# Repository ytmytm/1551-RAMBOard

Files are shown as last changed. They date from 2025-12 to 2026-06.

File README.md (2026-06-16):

# 1551-RAMBOard (First Bank)

This project adds **8K of RAM** and **8K of extra ROM space** to a **Commodore 1551** disk drive by replacing the ROM with a small daughterboard. The extra memory is used by a ROM patch to implement a simple **track cache**: read an entire track once, then serve subsequent sector reads from RAM.

A 27x (relative to 1541) / 7x (relative to 1551) fastloader is provided.

The mod and patched ROM are detected and utilized by [Parobek ROM](https://github.com/ytmytm/plus4-parobek).

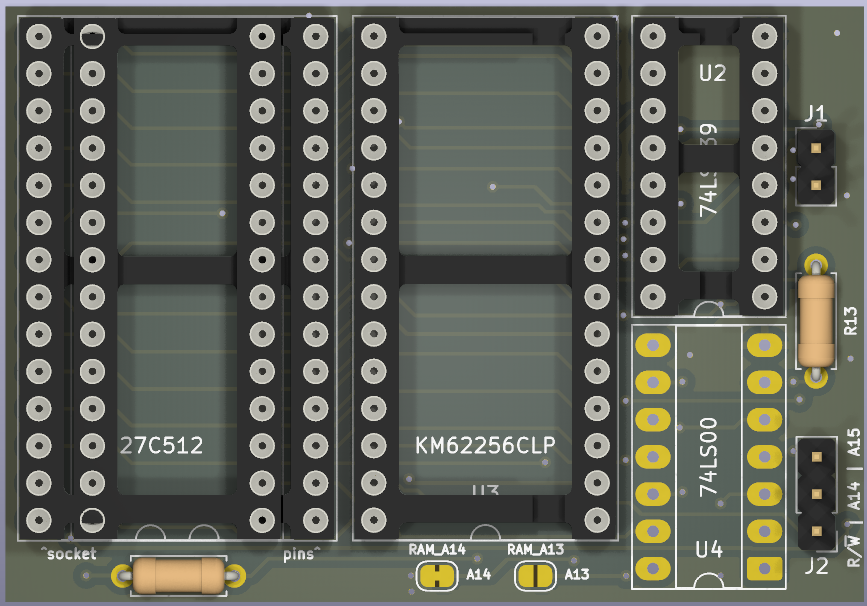
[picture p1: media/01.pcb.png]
1551-RAMBOard PCB


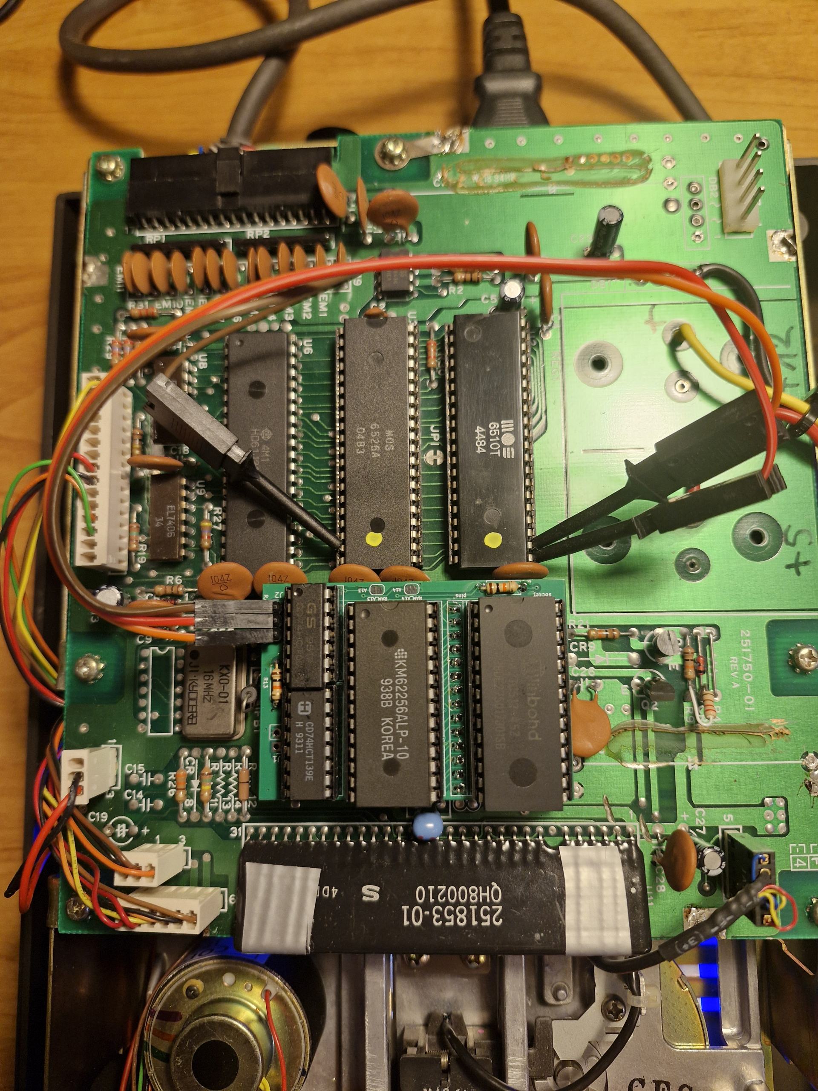
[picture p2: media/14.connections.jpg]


<a href="https://www.pcbway.com/project/shareproject/1551_RAMBOard_c846331a.html">PCB from PCBWay</a>

## What you get

- **RAM expansion**: `$8000-$9FFF` (8K) mapped to SRAM on the daughterboard.
- **Extra ROM window**: `$A000-$BFFF` (8K) mapped to the *upper* part of a larger ROM image.
- **Two DOS ROMs**: with a 64K ROM chip, you can add a switch to select either the stock 1551 ROM or the patched ROM
- **Two patched variants**: stock 1551 (318008-01) and [SuperDOS](https://plus4world.powweb.com/dl/utils/s/super_dos_1551.rom) (40-track disks)
- **HypaRAM**: fastloader
- **Parobek support**: even faster fastloader startup when drivecode is embedded in patched ROM

## Videos

<a href="https://www.youtube.com/watch?v=vWi2URbmIlo" target="_blank">
 Parobek loading 108 block file<small>Click for 1551 demonstration, loading a 108 block file</small></p>
</a>

<a href="https://www.youtube.com/watch?v=xZMYda7cszA" target="_blank">
 HypaRAM loading 220 block file<small>Click for Pi1551 HypaRAM demonstration, loading a 220 block file</small></p>
</a>

## Hardware

This board plugs into the original ROM socket and adds:

- **SRAM**: 8Kx8 (6264) or 32Kx8 (e.g. 62256). Only 8K is used by default; the remaining space is reserved for future banking options.
- **ROM**: 27C512/27E512 (64K). The board maps the active 32K half into `$8000-$FFFF`, but `$8000-$9FFF` is covered by RAM, so effectively the ROM is visible at `$A000-$FFFF` (24K). This is exactly the same setup as DolphinDOS on 1571
- **Glue logic**: `74LS139` + `74LS00`.

### BOM

- 1x 14-pin DIP socket
- 1x 16-pin DIP socket
- 2x 28-pin DIP socket
- 2x 14-pin round pinheaders ("precision" ones)
- 2x 10K resistors
- 1x 74LS00 (or HCT)
- 1x 74LS139 (or HCT)
- 1x 27E256 / 27E512 (32K or 64K EEPROM)
- 1x 6264 or 62256 (8K or 32K SRAM)
- 1x switch (for ROM selection: open or closed)

### Assembly

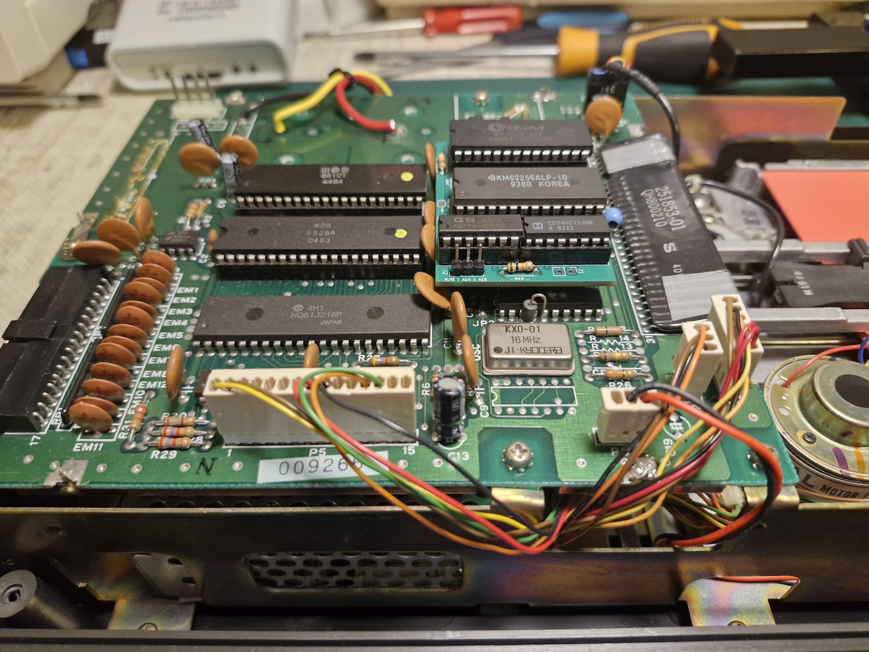
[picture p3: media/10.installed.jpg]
RAMBOard installed in a 1551


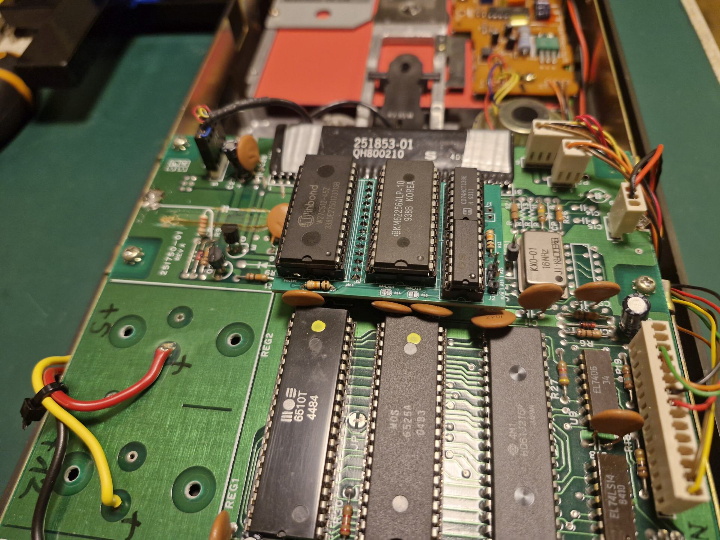
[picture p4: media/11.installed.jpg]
RAMBOard installed in a 1551


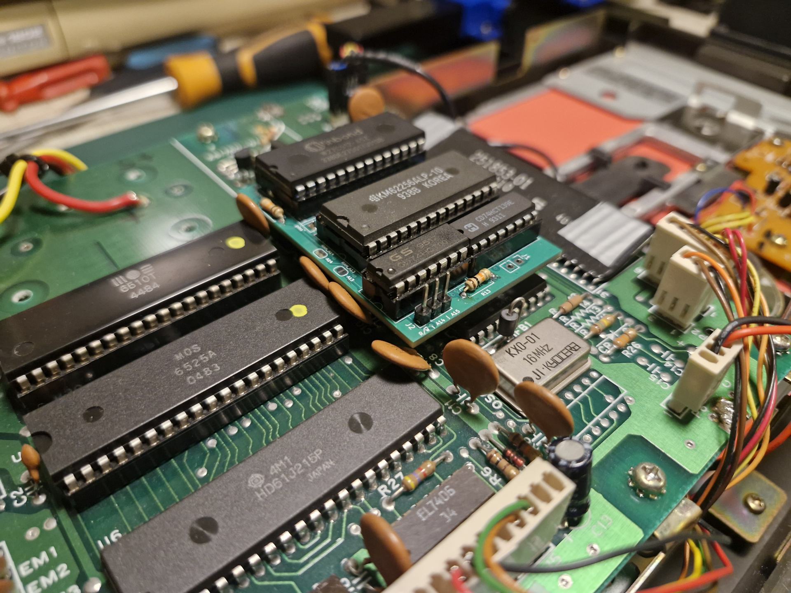
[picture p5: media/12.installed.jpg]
RAMBOard installed in a 1551


1. Start by soldering the pin headers to the holes marked "pins". Make sure their longer sections point toward the bottom. The board uses these to plug into the existing ROM socket.

2. Solder the remaining components: two resistors, then the sockets.

3. Flash the EEPROM with a ROM image from the Releases tab (or build your own with `make`). Use `1551.318008-01-64k.bin` for stock DOS or `super_dos_1551-64k.bin` for SuperDOS 40-track support. The 64K image contains the patched ROM in the top half (selected by default when `J1` is open), so you do not need to connect the switch yet.

4. Insert the chips into their sockets.

5. Open the 1551, remove the ROM chip (U4), and plug the board in its place. Ensure correct pin alignment.

6. Connect the remaining signals—`A14`, `A15`, and `R/~W`—as described in the Wiring section below.

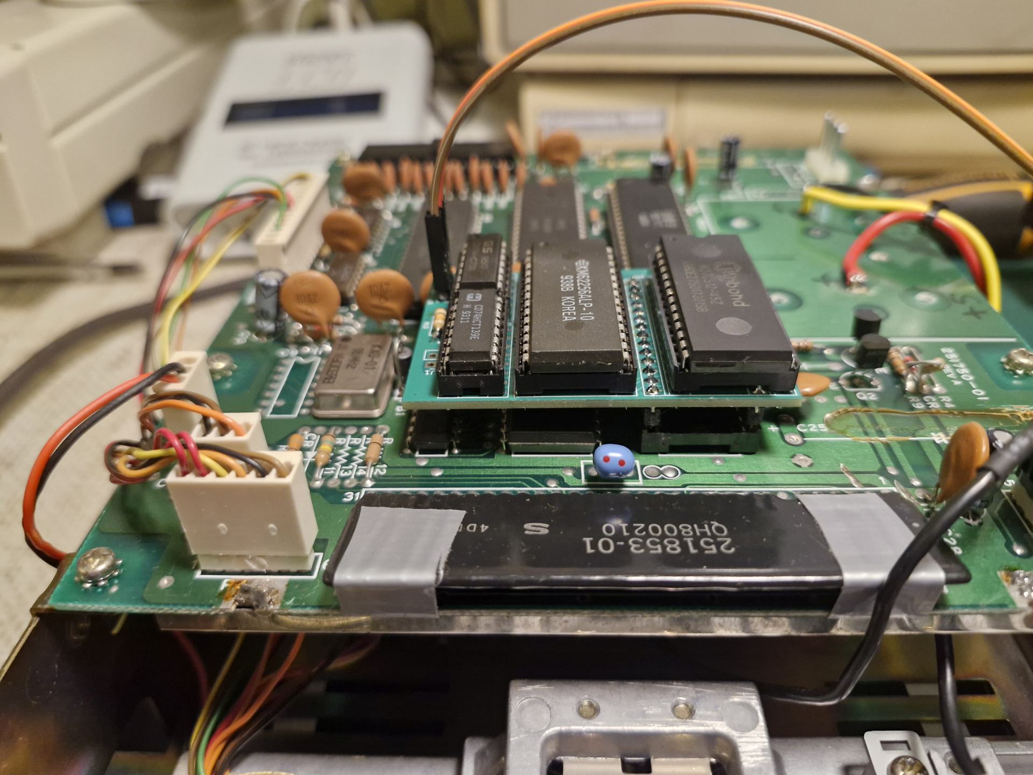
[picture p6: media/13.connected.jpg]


RAMBOard installed in a 1551

### Wiring

- **J1 (ROM bank select for 27C512)**:
  - **short**: bottom 32K of the 64K ROM
  - **open**: top 32K of the 64K ROM
- **J2 (3-wire tap from the 1551 mainboard)**:
  - **A14** from CPU **U2 pin 21** (or **U7 pin 7**)
  - **A15** from CPU **U2 pin 22** (or **U7 pin 6**)
  - **R/~W**: **do not** take raw R/W directly from the CPU. Use the qualified R/~W that actually goes to RAM:
    - onboard RAM **U5 pin 21**, or
    - **U3 pin 19**

### Jumpers

`RAM_A13` and `RAM_A14` jumpers are configured in such a way that you can plug in either SRAM 6264 (8K) or 62256 (32K) with no other changes.
If a method to latch two bits for the necessary port selection is found, then with 62256 (32K) four banks of 8K could be selected - e.g. for a permanent cache of the directory track.

### Quickstart

1. Install the hardware and keep J1 open
2. Use a 27E512 ROM with a 64K image from Releases (`1551.318008-01-64k.bin` or `super_dos_1551-64k.bin`)
3. Try running a simple BASIC program to read the ROM at `$a000` - with J1 open it should be the top, patched half with `RAM` signature
4. If you see `RAM` in the output and you can load the directory then everything works - directory track was already put into cache

```
10 open 15,8,15,"m-r"+chr$(0)+chr$(160)+chr$(3)
20 for i=1 to 3
30 get#15,b$
40 print asc(b$);b$
50 next
60 close 15
```

## Project files (KiCad)

Everything you need is attached to the Release page too.

- [KiCad project](kicad/1551-RAMBoard-FirstBank/)
- [Schematic PDF](kicad/1551-RAMBoard-FirstBank/plots/1551-RAMBoard2-FirstBank.pdf)
- [Gerbers](kicad/1551-RAMBoard-FirstBank/plots/)

## Firmware patch / build

The patcher is a single KickAssembler source file: `rampatch.asm`. It can patch either the stock 1551 ROM or SuperDOS 1551; the Makefile selects the base ROM via KickAssembler `-define` flags (`ROM1551` or `SUPERDOS1551`).

SuperDOS is the only other common 1551 DOS alternative. It adds 40-track disk support (similar in spirit to C64 SpeedDOS/DolphinDOS). The RAMBOard hook sites do not overlap with SuperDOS changes, so the same track-cache patch applies cleanly. Patch4 (ROM checksum bypass) is omitted for the SuperDOS build because SuperDOS already NOPs that routine.

### Source ROMs

Place these in `rom/` (or let `make` download them):

| File | Description |
|---|---|
| `rom/1551.318008-01.bin` | Stock 1551 DOS ([zimmers.net](https://www.zimmers.net/anonftp/pub/cbm/firmware/drives/new/1551/1551.318008-01.bin)) |
| `rom/super_dos_1551.bin` | SuperDOS 1551, 40 tracks ([plus4world](https://plus4world.powweb.com/dl/utils/s/super_dos_1551.rom)) |

### Windows (build.bat)

**Requirements**

- Java
- [KickAssembler](http://www.theweb.dk/KickAssembler/Main.html#frontpage) at `tools/KickAss.jar`
- Stock 1551 ROM at `rom/1551.318008-01.bin`

**Build**

```bat
build.bat
```

This builds the stock-ROM variant only:

- `1551.318008-01-patched.bin` — patched 32K ROM image
- `1551.318008-01-64k.bin` — 64K EPROM image (stock ROM in the lower half, patched ROM in the upper half)

For the SuperDOS variant, use the Linux Makefile (or invoke KickAssembler manually with `-define SUPERDOS1551`).

### Linux (Makefile)

**Requirements**

- `make`
- Java
- [KickAssembler](http://www.theweb.dk/KickAssembler/Main.html#frontpage) at `tools/KickAss.jar`
- [ACME](https://sourceforge.net/projects/acme-crossass/) assembler (`acme`)
- `curl` or `wget` (optional; used to auto-download source ROMs)

**Build everything**

```sh
make
```

This produces all deliverables:

| Output | Description |
|---|---|
| `1551.318008-01-patched.bin` | Patched 32K ROM (stock 1551 base) |
| `1551.318008-01-64k.bin` | 64K EPROM image (stock + patched) |
| `super_dos_1551-patched.bin` | Patched 32K ROM (SuperDOS 40-track base) |
| `super_dos_1551-64k.bin` | 64K EPROM image (SuperDOS + patched) |
| `hyparam_1551.prg` | HypaRAM fastloader wedge |

**Other targets**

```sh
make help          # list all targets
make superrom      # SuperDOS patched 32K + 64K images only
make clean         # remove all build outputs (keeps source ROMs in rom/)
make test          # VICE xplus4 with stock patched ROM + RAM expansion
make test-super    # VICE xplus4 with SuperDOS patched ROM + RAM expansion
```

Each 64K image is suitable for 27C512/27E512 EPROMs:

- First 16K: `$FF` bytes (EPROM neutral)
- Next 16K: unpatched base ROM (stock or SuperDOS)
- Upper 32K: patched ROM with track cache and fastloader

## HypaRAM fastloader wedge

An example fastloader wedge called **HypaRAM** is included in the `src/` directory as `hypainstall14f0.s`, which
generates `hyparam_1551.prg`.

When loaded it will intercept LOAD operations and will run the fastloader embedded in the patched drive ROM directly.
With track cache the speedup is approximately **27x** relative to 1541 and **7x** relative to stock 1551.

For simplicity it supports only device #8 and doesn't check if the ROM was patched.

The same fastloader is embedded in [Parobek ROM](https://github.com/ytmytm/plus4-parobek) and will be autodetected for LOAD operations.

### Building HypaRAM

To build the binary `hyparam_1551.prg`, you need the [ACME assembler](https://sourceforge.net/projects/acme-crossass/).

- **Windows**:  
  ```
  acme hypainstall14f0.s
  ```

- **Linux/Unix/WSL**:  
  ```
  make
  ```

The produced binary `hyparam_1551.prg` can be loaded into C16/+4 emulators or real hardware with the RAMBoard installed.

## Testing in VICE

This repo contains `docs/vice-1551-ram-expansion.patch`, which documents the changes needed for VICE to emulate:

- 1551 RAM expansion at `$8000-$9FFF`
- the 32K ROM mapping with RAM overlay

## ROM signature / API stub

The patched ROM contains a small fixed-location signature and a public jump table:

- `$A000-$A002`: ASCII signature `"RAM"` (used to detect that the patched ROM is active)
- `$A003...`: jump table entries

This is used by the HypaRAM fastloader and [Parobek ROM](https://github.com/ytmytm/plus4-parobek).

## Theory of operation

### Address space

The onboard logic enables ROM only in `$C000-$FFFF` range. We ignore this signal and instead use CPU's A15 line as a trigger which signals that `$8000-$FFFF` range is being accessed.

The 74LS139 logic uses A14 to further divide that range to generate chip select signals for RAM in `$8000-$9FFF` range and for ROM in `$A000-$FFFF`.

### Track cache logic

When the drive firmware requests a sector read:

- If the requested track is already cached, the sector is copied from expanded RAM into the target buffer and execution returns to the original ROM flow.
- Otherwise, the patched code reads the entire track, caching **decoded sector data** in expanded RAM and collecting sector numbers from headers to build the lookup table.

The whole track is captured within **one disk revolution** (about **200 ms at 300 rpm**).

### GCR decoding on 1551

Unlike 1541-class drives, the 1551 ROM already decodes GCR **on the fly** during reads (made possible by the 2 MHz CPU). The patch reuses the same approach.

## Related

- design for 1541: [**1541-RAMBOard**](https://github.com/ytmytm/1541-RAMBOardII)
- design for 1571: [**1571 Track Cache ROM**](https://github.com/ytmytm/1571-TrackCacheROM)

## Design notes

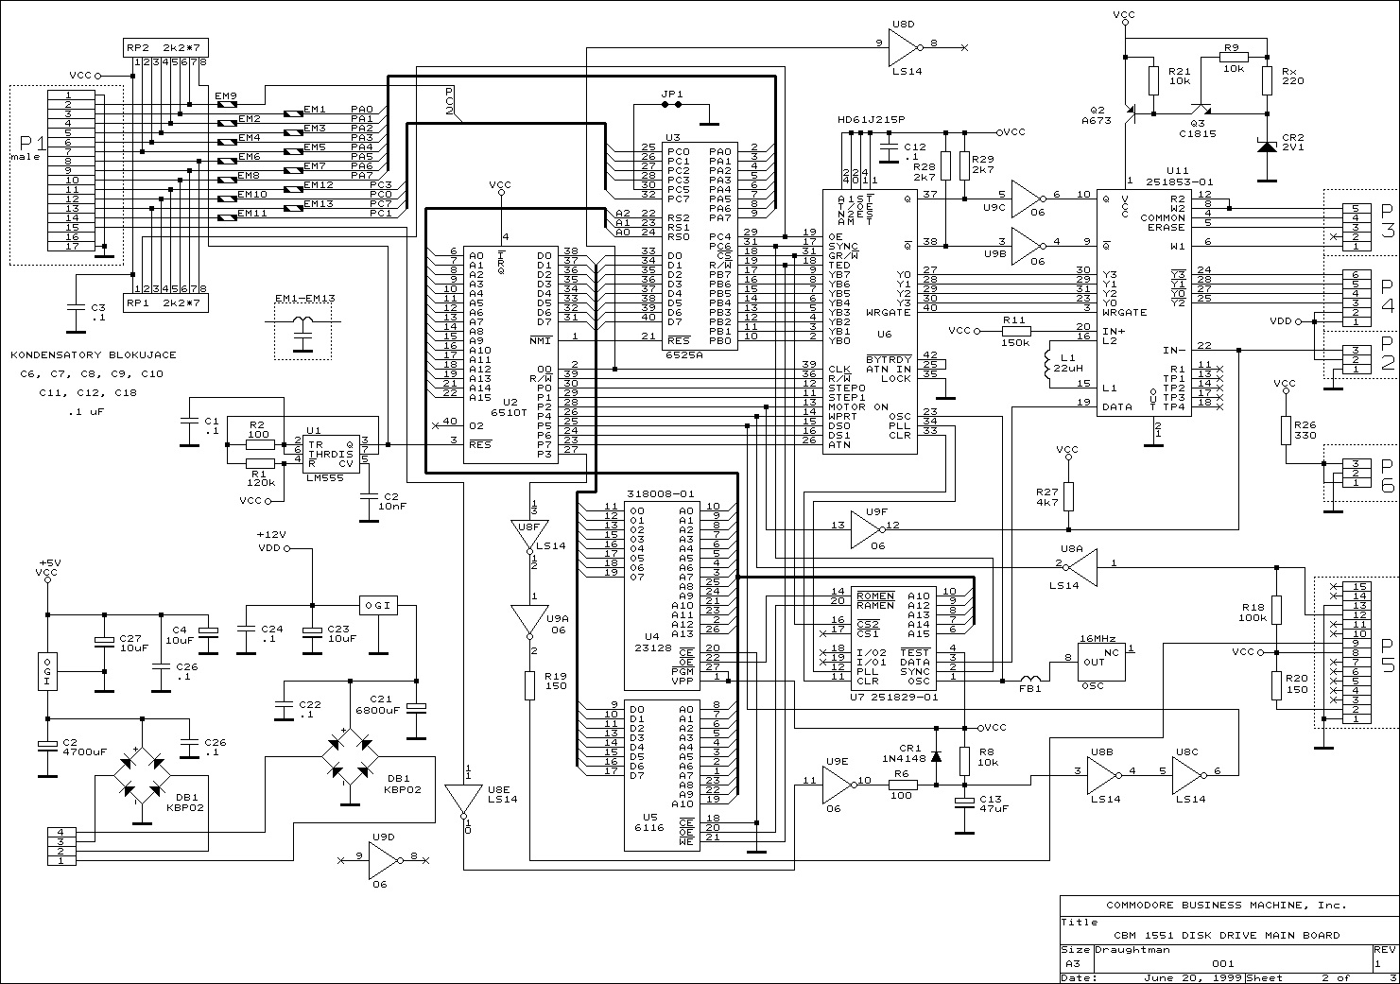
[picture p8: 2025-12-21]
doc/1551-schematic-main.gif

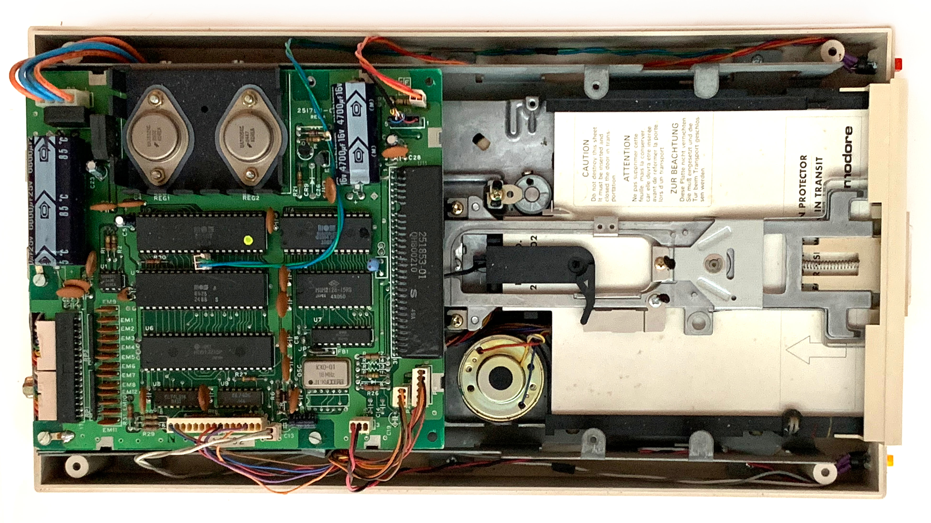
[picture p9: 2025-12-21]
doc/1551-1570_inside.jpg

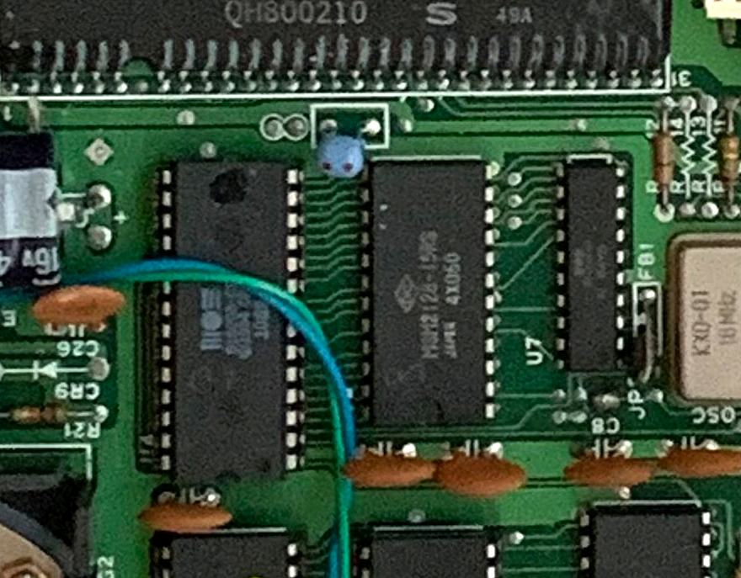
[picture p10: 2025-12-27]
doc/1551-1570_inside-trim.jpg

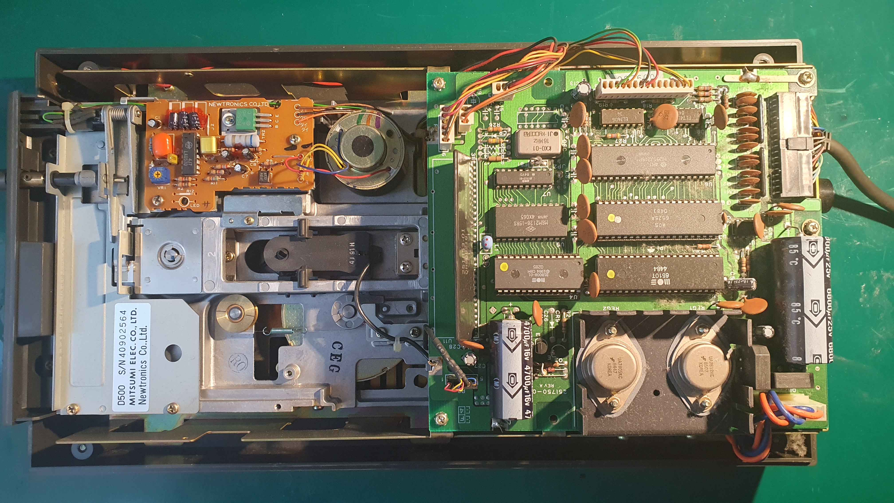
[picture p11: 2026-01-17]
doc/nightrider-1551-1.jpg

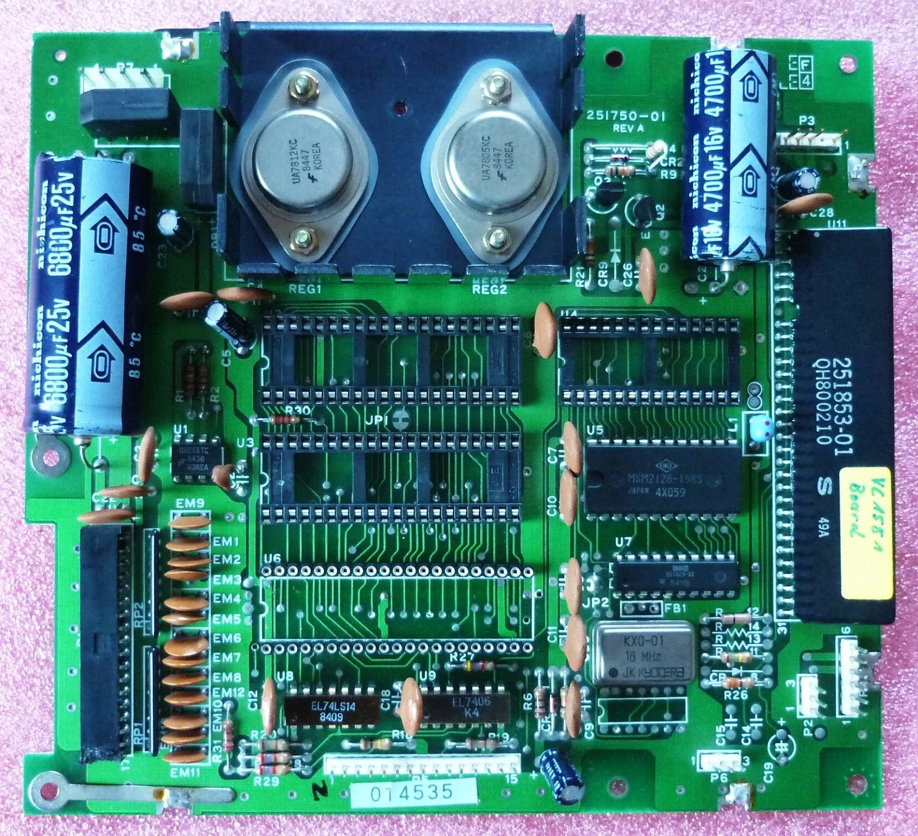
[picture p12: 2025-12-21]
doc/1551-s-l1600.jpg

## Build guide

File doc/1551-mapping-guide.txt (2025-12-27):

(Note: this is an automatic comparison based on 1551 disassembly and All About Your 1541
       trust but verify!)

COMMODORE 1541 TO 1551 ROM MAPPING GUIDE
========================================

This document provides a comprehensive mapping between the Commodore 1541 and 1551 ROMs
to facilitate porting low-level patches (like RAMBoard/RAMEXP patches).

1. ZERO PAGE MAPPING
--------------------
The 1551 zero page is significantly shifted compared to the 1541.

| Description | 1541 Addr | 1551 Symbol | 1551 Addr |
|---|---|---|---|
| Active Track Pointer | $32 | zp20 | $20 |
| Active Sector Pointer | $33 | zp21 | $21 |
| Buffer Pointer (Current) | $30-$31 | zp27-$28 | $27-$28 |
| Header ID 1 & 2 | $16-$17 | zp18-$19 | $18-$19 |
| Header Track | $18 | zp1A | $1A |
| Header Sector | $19 | zp1B | $1B |
| Header Checksum | $1A | zp1C | $1C |
| Data Block ID (default $07) | $47 | zp41 | $41 |
| Data Parity (Checksum) | $3A | zp30 | $30 |
| Current Drive Number (always 0) | $7F | zp78 | $78 |
| GCR conversion offset | $34 | zp2D | $2D |
| GCR conversion pointer | $2E-$2F | zp1E-$1F | $1E-$1F |
| GCR byte counter | $36 | zp2E | $2E |
| GCR buffer pointer | $4E-$4F | zp36-$37 | $36-$37 |

Note: 1551 has "free" ZP space at $F0-$FF and around $60-$6F (though check disassembly).

2. HARDWARE I/O MAPPING
-----------------------
The 1551 replaces VIAs with a TIA chip ($4000) and CPU Port ($00/$01).

| Feature | 1541 (VIA) | 1551 (TIA/Port) | Logic Difference |
|---|---|---|---|
| Data Input | $1C01 | $4001 | TIA read register |
| SYNC Found | $1C00 bit 7 | $4002 bit 6 | 1551: 0 = SYNC found |
| Byte Ready | $1800 (CA1) | $01 bit 7 | 1551: 1 = Byte Ready |
| Motor / LED | $1C00 bits 2/3  | $01 bits 2/3 | Same bit positions |
| Stepper Motor | $1C00 bits 0/1  | $01 bits 0/1 | Same bit positions |
| R/W Mode | $1C00 bit 5 | $4002 bit 4 | 0=Write, 1=Read |

3. ROM FUNCTION MAPPING
-----------------------
Addresses refer to stock 1541-II ($C000-$FFFF) and 1551 ($C000-$FFFF).

| 1541 Routine | 1541 Addr | 1551 Addr | 1551 Symbol | Notes |
|---|---|---|---|---|
| Read Sector | $F4D1 | $F403 | B_F403 | Main sector read entry point |
| Wait for Data Block| $F50A | $F513 | S_F513 | Wait for header sync + sync |
| Wait for Header | $F510 | $F519 | S_F519 | Look for specific track/sector header|
| Wait for SYNC | $F556 | $F560 | L_F560 | Simple wait for SYNC mark |
| Encode Header | $F934 | $F3BB | S_F3BB | Result goes to $0111 on 1551 |
| Calculate Parity | $F5E9 | $F60A | S_F60A | Result in A and zp30 |
| Error Termination  | $F969 | $FA12 | L_FA12 | Exit to main loop with error in A |
| Initialize Drive | $D005 | $C4B7 | S_C4B7 | Disk initialization routine |
| 5 GCR to 4 BIN | $F7E6 | $F928 | S_F928 | Fast GCR decoding routine |
| ROM Checksum Check | $EAE4 | $E9F0 | B_E9F0 | Site to disable ROM checksum |

4. CODE STRUCTURE COMPARISON (SECTOR READ)
------------------------------------------

1541 (Standard Sector Read loop):
---------------------------------
F4D1: 20 0A F5    JSR $F50A  ; Wait for data block
F4D4: AD 01 1C    LDA $1C01  ; Read data...

1551 (Standard Sector Read loop):
---------------------------------
F403: 20 13 F5    JSR $F513  ; Wait for block (S_F513)
F406: 24 01       BIT $01    ; Wait for byte ready (zp01 bit 7)
F408: 10 FC       BPL $F406
F40A: AD 01 40    LDA $4001  ; Read from TIA data register

5. PATCH ADVICE FOR 1551
------------------------
- Hooking Read Sector: Use $F403 instead of $F4D1.
- GCR Decoding: 1551 uses "on-the-fly" decoding in the ROM ($F406 onwards), unlike 1541 which reads the whole GCR block and decodes later ($F4ED).
- Checksum Disable: Disable at $E9F2 by NOPing the branch or forcing the comparison to pass.
- Free RAM: $0300-$06FF (4 buffers) is the same. BAM is resident at $0700-$07FF.

6. PROPOSED RAMPATCH-1551.ASM HEADER
------------------------------------
This is how the configuration section of `rampatch-1541.asm` translates to 1551.

```6502
// 1551 ROM patch configuration
// RAM expansion base address (e.g. $8000-$9FFF)
.const RAMEXP = $8000 

// Zero Page mapping (1551 equivalents)
.const HEADER = $18   // block header id 1 ($18-$1C: ID1, ID2, T, S, CHK)
.const HDRPNT = $20   // active track/sector pointer ($20/$21)
.const STAB   = $24   // scratch pad for GCR conversion ($24-$2B)
.const BUFPNT = $27   // current buffer pointer ($27/$28)
.const DBID   = $41   // data block ID char ($07)
.const CHKSUM = $30   // parity for data buffer (result of S_F60A)

// 1551 ROM locations
.const LC4B7 = $C4B7 // initialize drive if needed
.const LC722 = $C722 // initialize drive (raw entry)
.const LF560 = $F560 // wait for sync
.const LF928 = $F928 // convert 5 GCR bytes to 4 BIN
.const LF513 = $F513 // wait for encoded header & sync
.const LF406 = $F406 // instruction after patch at $F403
.const LF60A = $F60A // calculate parity of data block ($27 pointer)

// Patch variables (using verified free ZP in 1551)
.const bufpage     = $f0  // (2)
.const bufrest     = $f2  // (2) - only if caching raw GCR
.const hdroffs     = $f4  // (1)
.const counter     = $f5  // (1)
.const hdroffsold  = $f6  // (1)

// ROM Patch Sites
.const PATCH_READ_SECTOR  = $F403  // hook for ReadSector (was $F4D1)
.const PATCH_DISK_CHANGE   = $C722  // hook for ResetCache (was $C649)
.const PATCH_ROM_CHECKSUM  = $E9F0  // 6x NOP to disable check (was $EAE4)
.const PATCH_JOB_IRQ       = $F19F  // hook for InvalidateCacheForJob (was $F2C0)
.const PATCH_I_COMMAND     = $D121  // hook for InitializeAndResetCache (was $D005)

// Sizes (1551 uses same sector counts as 1541)
.const hdrsize     = 8
.const maxsector   = 22
.const bufrestsize = $48
```

7. DETAILED CORRESPONDENCE TABLE
-------------------------------

| Feature / Variable | 1541 Address | 1551 Address | 1551 Disasm Symbol |
|---|---|---|---|
| Disk ID 1 | $12 | $14 | zp14 |
| Disk ID 2 | $13 | $15 | zp15 |
| Header ID 1 | $16 | $18 | zp18 |
| Header ID 2 | $17 | $19 | zp19 |
| Header Track | $18 | $1A | zp1A |
| Header Sector | $19 | $1B | zp1B |
| Header Checksum | $1A | $1C | zp1C |
| Drive Status | $20 | $2B | zp2B |
| Current Track | $22 | $29 | zp29 |
| Current Sector | $4C | $3D | zp3D |
| Job Buffers | $00-$05 | $0002-$0007  | $0002-$0007 |
| Job Parameters | $06-$11 | $08-$13 | zp08-zp13 |
| DOS Error Flag | $0298 | $0298 | V_0298 |
| TIA Register Port  | $1C01 (VIA)  | $4001 (TIA)  | V_4001 |
| SYNC Status | $1C00 bit 7  | $4002 bit 6  | V_4002 (0=found)  |
| Byte Ready Status  | $1800 (CA1)  | $01 bit 7 | zp01 (1=ready) |
| Buffer Pointer | $9A (table)  | $9A (table)  | zp9A |
| Buffer Allocation  | $A8 (table)  | $A8 (table)  | zpA8 |
| Channel Index | $022B-$022D  | $022B-$022D  | V_022B |
| File Type | $ED (table)  | $ED (table)  | zpED |
| Channel Status | $F3 (table)  | $F3 (table)  | zpF3 |
| Blocks Free (lo) | $02FA | $02FA | V_02FA |
| Blocks Free (hi) | $02FC | $02FC | V_02FC |
| BAM Changed Flag | $0251 | $0251 | V_0251 |
| Command Flag | $0255 | $0255 | V_0255 |
| End Pointer | $0244 | $0244 | V_0244 |

8. GCR DECODING ANALYSIS
------------------------

### 8.1 On-the-fly Decoding
Unlike the 1541 (1MHz), which must read a whole track of raw GCR data and decode it later, the 1551 (2MHz) performs **on-the-fly GCR decoding** similar to the 1571.
- The TIA chip ($4001) latches the incoming GCR byte.
- The 2MHz CPU has enough cycles between bytes to decode the GCR nybbles using lookup tables.
- **Implication for RAMpatch**: In your `ReadTrack` routine, you should decode GCR into binary data *while reading*. This allows the cache to store ready-to-use binary data, significantly speeding up subsequent sector requests.

### 8.2 GCR Decoding Tables (1551 vs 1571)
You noticed that 1571 tables take 1KB while 1551 tables seem shorter.
- **1571 (4 Pages)**: The 1571 ROM ($9F0D-$A3FF) uses four separate 256-byte pages for GCR decoding. However, these pages are highly redundant (e.g., the same 64-byte sequence repeated 4 times per page).
- **1551 (1 Page)**: The 1551 ROM ($F6FF-$F7FF) uses an **overlapping table** technique. It fits the same decoding logic into a single 256-byte page by using different base addresses (offsets) into the same block of data.
  - 1571 `LA00D` (Page 0) -> 1551 uses base `$F70C,X`
  - 1571 `LA10D` (Page 1) -> 1551 uses base `$F70D,X` or `$F70E,X`
  - 1571 `LA20D` (Page 2) -> 1551 uses base `$F71C,X`
  - 1571 `LA30D` (Page 3) -> 1551 uses base `$F729,X`
- **Recommendation**: Do not bundle GCR tables in your 1551 patch. Use the existing tables in the 1551 ROM starting at `$F6FF`.

### 8.3 Comparison of GCR base addresses:
| 1571 Label | 1571 Addr | 1551 Equivalent Base | 1551 Addr |
|---|---|---|---|
| L9F0D | $9F0D | V_F70C | $F70C |
| L9F1D | $9F1D | V_F71C | $F71C |
| LA00D | $A00D | V_F70C | $F70C |
| LA10D | $A10D | V_F70D / V_F70E | $F70D/E |
| LA20D | $A20D | V_F71C | $F71C |
| LA30D | $A30D | V_F729 | $F729 |
| L9F2A | $9F2A | V_F729 | $F729 |

9. ADDITIONAL FUNCTION MAPPINGS
--------------------------------
Based on detailed analysis of the commented disassembly:

| 1541 Routine | 1541 Addr | 1551 Addr | 1551 Symbol | Notes |
|---|---|---|---|---|
| Open Channel (Read) | ~$D1FB | $D1FB | S_D1FB | Opens channel for reading files |
| Open Channel (Write) | ~$D217 | $D217 | S_D217 | Opens channel for writing files |
| Get File Type | ~$D235 | $D235 | S_D235 | Returns file type, Z flag if REL |
| Get Byte from Buffer | ~$D247 | $D247 | S_D247 | Reads next byte from channel buffer |
| Read Track/Sector Link | ~$D1AB | $D1AB | S_D1AB | Reads track/sector from linked file |
| Read/Write Block | ~$D1D3 | $D1D3 | S_D1D3 | Common entry for block operations |
| Main Wait Loop | ~$EAxx | $EABD | L_EABD | Idle loop waiting for commands |
| Periodic Maintenance | ~$EAxx | $EADC | S_EADC | Called every 256 idle loops |
| Clear Error Flag | ~$F3xx | $F3F0 | S_F3F0 | Clears V_026C error flag |
| Set LED Flag | ~$F3xx | $F3F7 | L_F3F7 | Sets LED flash mode ($E0) |
| Header Timeout | ~$F554 | $F554 | B_F554 | Header search timeout (error $02) |
| Sync Timeout | ~$F556 | $F55B | L_F55B | Sync wait timeout (error $03) |
| TCBM Bus Handler | N/A | $C022 | S_C022 | 1551-specific TCBM interrupt handler |
| TCBM TALK/LISTEN | N/A | $C071 | B_C071 | Handle TALK/LISTEN commands |
| TCBM Data Receive | N/A | $C0F6 | B_C0F6 | Handle incoming data |
| TCBM Data Send | N/A | $C14E | B_C14E | Handle outgoing data |

10. TCBM PROTOCOL DETAILS (1551-SPECIFIC)
------------------------------------------
The 1551 uses TCBM (TED Computer Bus Manager) instead of IEEE-488 serial bus.

TCBM Hardware Registers:
- $4000: TIA Port A (data port, bidirectional)
- $4001: TIA Data Latch (GCR bytes from disk)
- $4002: TIA Status/Control Register
  * Bit 6: SYNC found (0 = found, inverted logic vs 1541)
  * Bit 3: ACK handshake bit
  * Bits 6-7: Stepper motor control
- $4003: TIA Data Direction Register (0=input, $FF=output)
- $01: CPU Port (bit 7 = Byte Ready, bits 0-1 = stepper, bit 2 = motor, bit 3 = LED)

TCBM Command Codes:
- $40: TALK command
- $20: LISTEN command  
- $5F: UNTALK command
- $3F: UNLISTEN command
- $60: DATA (not a device command)

TCBM Handshake:
- DAV (Data Valid): Bit 7 of $4002 (negative logic: 0 = data valid)
- ACK: Bit 3 of $4002 (set/clear for handshake)
- Double-read technique: Read $4000 twice to ensure port stability

11. IRQ AND JOB QUEUE DIFFERENCES
----------------------------------
1541 IRQ ($F2C0):
- Triggered by IEEE-488 ATN line
- Processes job queue at $00-$05
- Checks for ATN commands from computer

1551 IRQ ($F195):
- Triggered by 555 timer (astable multivibrator)
- Frequency: According to disassembly, IRQ occurs every 16650 cycles
  * At 2MHz: 16650 cycles / 2000000 cycles/s = 8.325ms between IRQs
  * This theoretically gives ~120Hz (1/0.008325), BUT:
  * - There is no direct technical documentation confirming this frequency
  * - Some sources suggest ~100Hz (every 10ms)
  * - 555 timer may have tolerance, so actual frequency may vary
  * - Should be verified by measurement or technical documentation
- Processes job queue at $0002-$0007 (shifted by 2 bytes)
- Handles LED flashing, stepper motor control, job processing
- No IEEE-488 equivalent (uses TCBM polling instead)

Job Buffer Structure:
- 1541: $00-$05 (6 job buffers)
- 1551: $0002-$0007 (6 job buffers, shifted)
- Job codes: $80 = read, $90 = write, $01 = empty

12. BUFFER AND CHANNEL MANAGEMENT
----------------------------------
Buffer Allocation Tables:
- 1541: $A8 (buffer allocation), $AF (alternate pointer), $9A (buffer pointers)
- 1551: $A8 (buffer allocation), $AF (alternate pointer), $9A (buffer pointers)
- Same structure, but addresses may differ slightly

Channel Management:
- 1541: $022B-$022D (logical index for channels 0-2)
- 1551: $022B-$022D (logical index for channels 0-14)
- Channel status: $FF = not open, bit 7 = allocated, bits 0-3 = buffer number

File Type Table:
- 1541: $ED (file type per channel)
- 1551: $ED (file type per channel)
- Types: $00=DEL, $01=SEQ, $02=PRG, $03=USR, $04=REL

13. GCR DECODING ALGORITHM DETAILS
-----------------------------------
The 1551 on-the-fly decoding process ($F403):

1. Wait for header sync and verify header block (S_F513)
2. Wait for sector data sync mark (L_F560)
3. Read and decode 256 bytes + 4 bytes overhead:
   - Loop: Read 5 GCR bytes → decode to 4 binary bytes
   - Uses overlapping tables: V_F70C, V_F70D, V_F70E, V_F71C, V_F729, V_F6FF
   - Temporary variables: zpFA-zpFD ($FA-$FD) for GCR byte processing
4. Verify checksum:
   - First decoded byte must be $07 (data block marker)
   - Calculate XOR checksum of 256 bytes (S_F60A)
   - Compare with decoded checksum byte

GCR Decoding Process (5 bytes → 4 bytes):
- Byte 1: Bits from GCR bytes #1 and #2 (uses V_F70C)
- Byte 2: Bits from GCR bytes #2 and #3 (uses V_F70C + offsets)
- Byte 3: Bits from GCR bytes #3 and #4 (uses V_F71C, V_F70C+1)
- Byte 4: Bits from GCR bytes #4 and #5 (uses V_F729, V_F6FF)

14. HEADER ENCODING DETAILS
----------------------------
Header Structure (5 bytes → 8 GCR bytes):
- Byte 0: $08 (header marker)
- Byte 1: zp1C (header checksum)
- Byte 2: zp1B (sector number)
- Byte 3: zp1A (track number)
- Byte 4: zp19 (disk ID byte 2)
- Byte 5: zp18 (disk ID byte 1)
- Bytes 6-7: $00 (padding)

Encoding Process (S_F3BB):
- First 4 bytes → 5 GCR bytes (stored at $0111-$0115)
- Last 4 bytes → 5 GCR bytes (stored at $0116-$011A)
- Uses S_F80C (encode 4 binary → 5 GCR)
- Result: 8 GCR bytes total at $0111-$011A (vs $0024-$002B on 1541)

15. ERROR CODES AND STATUS
---------------------------
Error Codes (returned in accumulator):
- $01: Success
- $02: Header not found (timeout after $5A retries)
- $03: Sync not found (timeout)
- $04: Wrong block marker (not $07)
- $05: Checksum mismatch

Error Handling:
- Error code stored in job buffer ($0002,Y on 1551, $00,Y on 1541)
- Error flag: V_026C (same address on both)
- LED flashing: Set zp76 to $E0 for error indication
- Flash rate: ~250ms (30 IRQ cycles at ~120Hz)

16. ADDITIONAL ZERO PAGE VARIABLES
-----------------------------------
Temporary Variables (GCR processing):
- zpFA ($FA): First GCR byte / temp storage
- zpFB ($FB): Second GCR byte / temp storage
- zpFC ($FC): Third GCR byte / temp storage
- zpFD ($FD): Fourth GCR byte / temp storage
- zpF9 ($F9): Decoded nybble storage

IRQ and Status Variables:
- zp3A ($3A): Saved stack pointer (1541: $49)
- zp3C ($3C): Retry counter (used instead of X register)
- zp3F ($3F): GCR/BIN indicator (1541: $50)
- zp76 ($76): LED flag ($E0 = flash mode)
- zp55 ($55): LED flash counter
- zp96 ($96): LED timeout counter
- zp97 ($97): TIA status/ACK bits

TCBM Communication:
- zp58 ($58): Pending data flag (bit 7 set = data pending)
- zp59 ($59): Last data byte (saved for delayed processing)
- zp5B ($5B): TALK flag
- zp5C ($5C): LISTEN flag
- zp7C ($7C): Secondary address
- zp7D ($7D): Secondary address backup
- zp7E ($7E): Data byte storage
- zp8F ($8F): Command byte storage
- zp95 ($95): EOI flag

Stepper Motor Control:
- zp29 ($29): Current track (FDC track register)
- zp3B ($3B): Stepper motor direction (<$80 = inner, >=$80 = outer)
- zp38 ($38): TIA control register bits (for stepper)
- zp2B ($2B): Drive status flag (bit 5=motor, bit 6=stepper, bit 7=ready)

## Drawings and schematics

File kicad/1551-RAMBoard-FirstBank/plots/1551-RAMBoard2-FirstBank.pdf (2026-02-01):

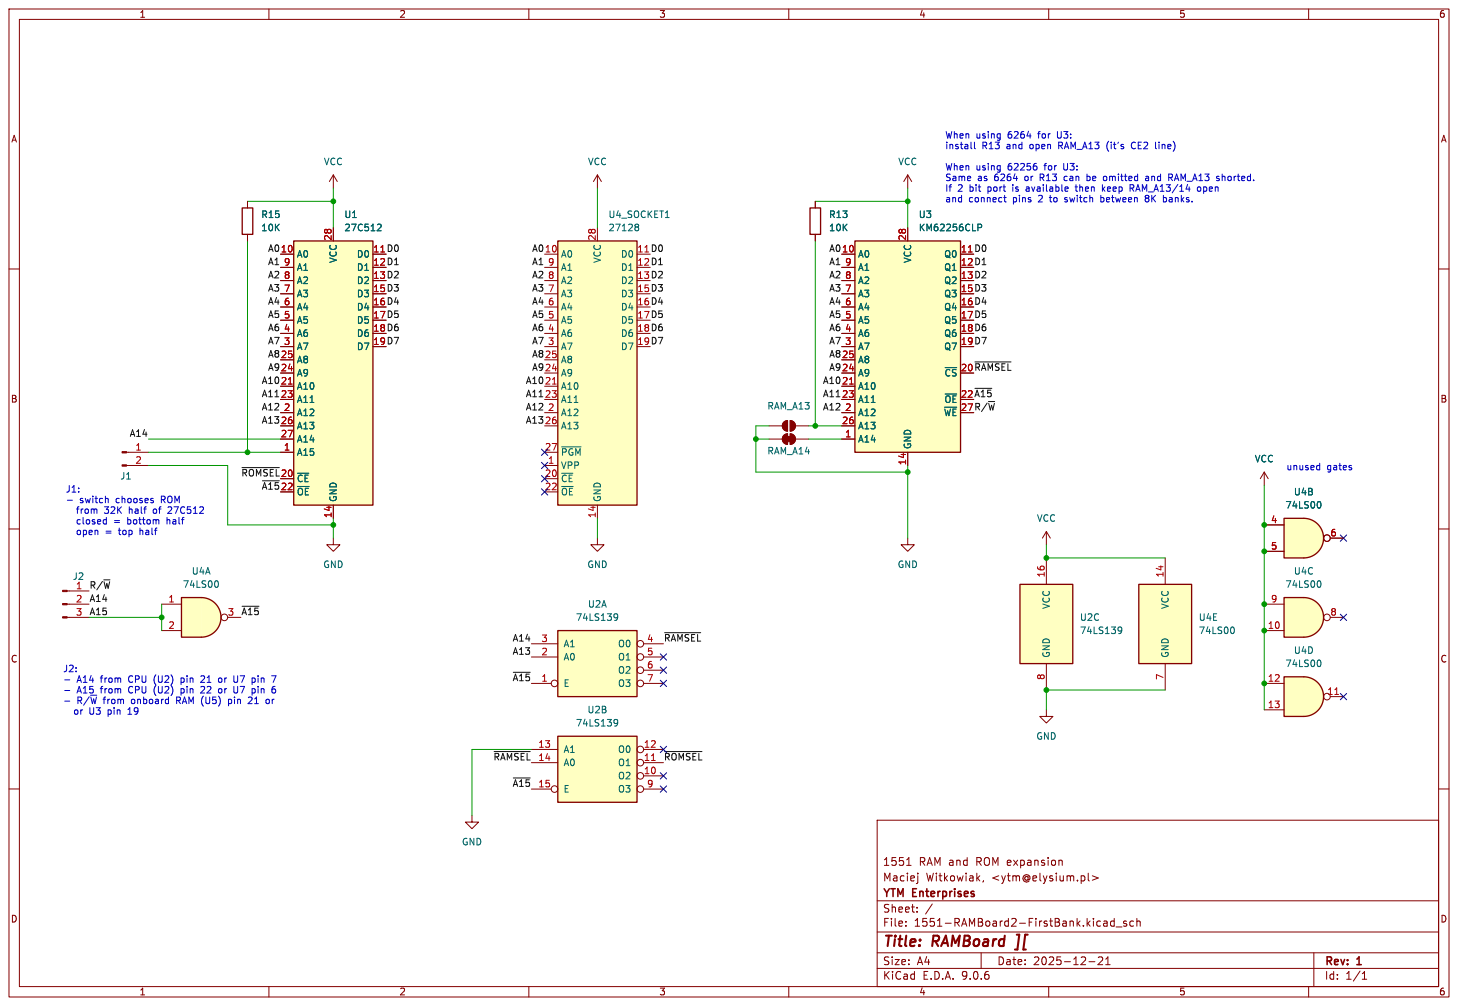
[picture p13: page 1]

and connect pins 2 to switch between 8K banks. J2: - A14 from CPU (U2) pin 21 or U7 pin 7

- A15 from CPU (U2) pin 22 or U7 pin 6
- R/~{W}from onboard RAM (U5) pin 21 or or U3 pin 19

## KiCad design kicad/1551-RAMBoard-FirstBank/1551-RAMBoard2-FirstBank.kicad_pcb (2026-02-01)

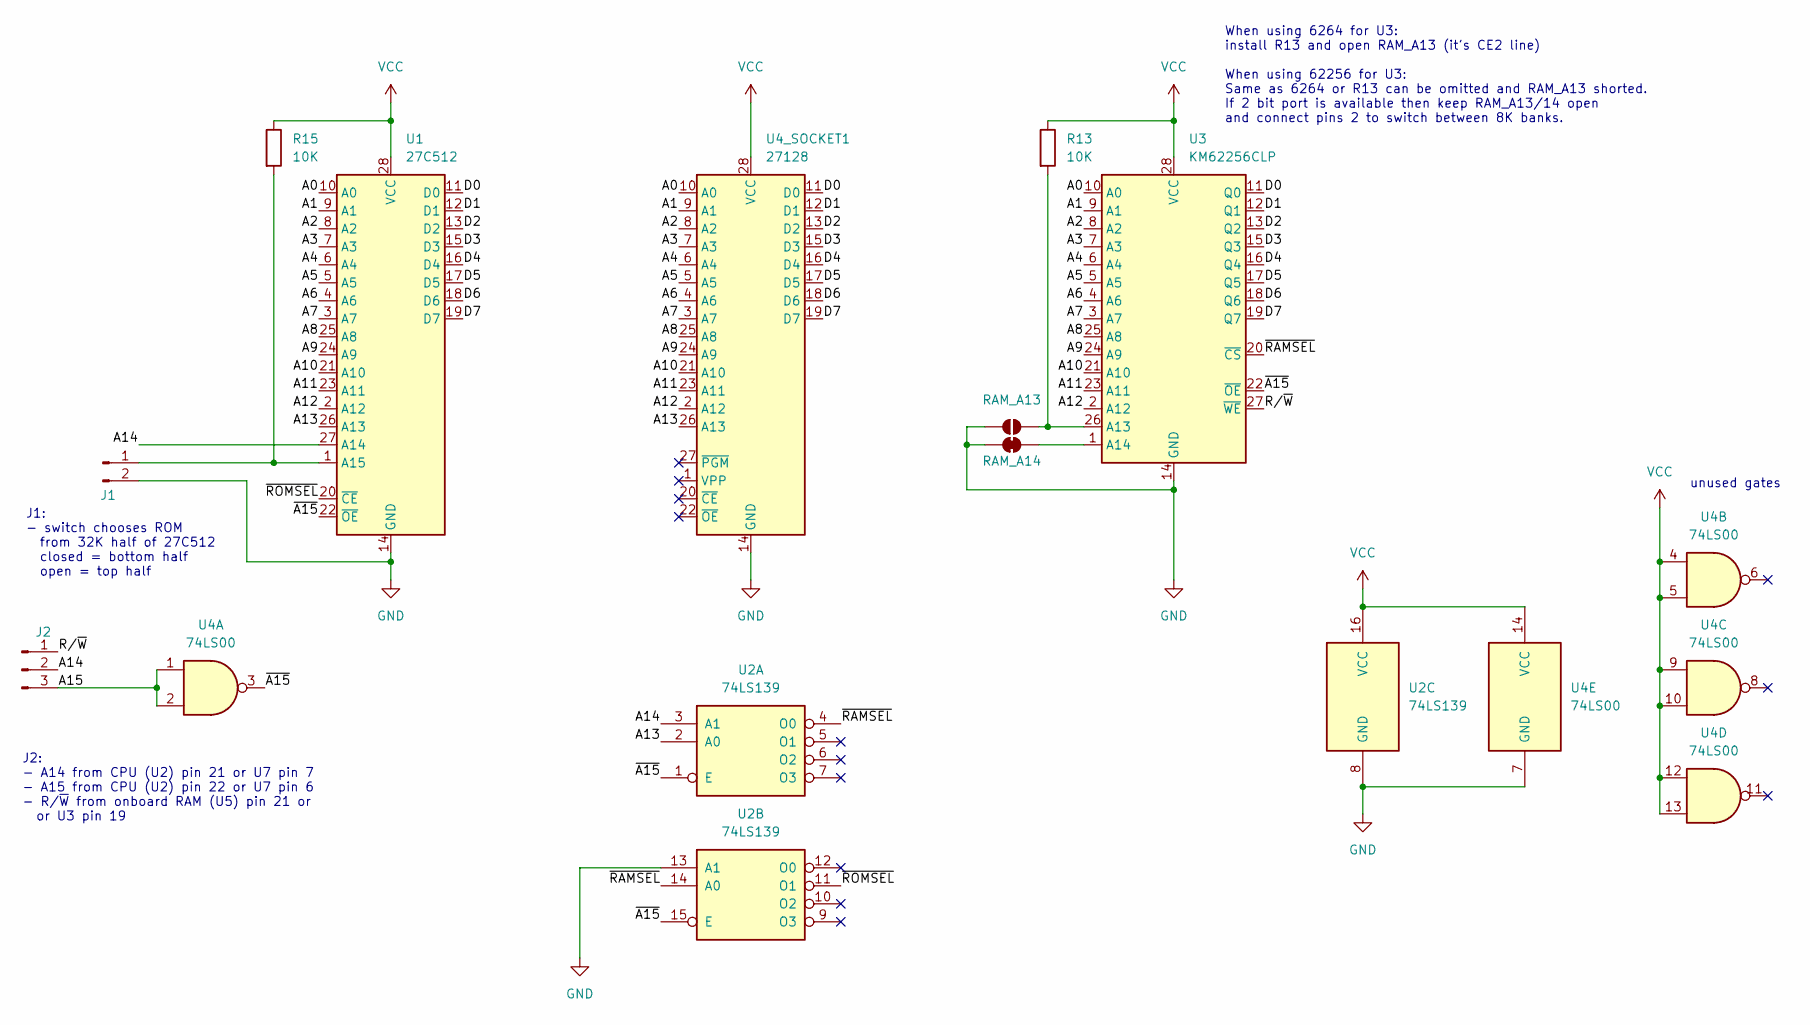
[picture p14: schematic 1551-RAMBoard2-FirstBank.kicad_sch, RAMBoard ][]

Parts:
J1: Conn_01x02_Pin; PinHeader_1x02_P2.54mm_Vertical
J2: Conn_01x03_Pin; PinHeader_1x03_P2.54mm_Vertical
R13, R15: 10K; R_Axial_DIN0207_L6.3mm_D2.5mm_P7.62mm_Horizontal
RAM_A13: SolderJumper_2_Open; SolderJumper-2_P1.3mm_Open_RoundedPad1.0x1.5mm
RAM_A14: SolderJumper_2_Bridged; SolderJumper-2_P1.3mm_Bridged_RoundedPad1.0x1.5mm
U1: 27C512; DIP-28_W15.24mm_Socket_LongPads
U2: 74LS139; DIP-16_W7.62mm_Socket_LongPads
U3: KM62256CLP; DIP-28_W15.24mm_Socket_LongPads
U4: 74LS00; DIP-14_W7.62mm_Socket_LongPads
U4_SOCKET1: 27128; DIP-28_W15.24mm_Socket_LongPads

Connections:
/A0: U1.10 (A0), U3.10 (A0), U4_SOCKET1.10 (A0)
/A1: U1.9 (A1), U3.9 (A1), U4_SOCKET1.9 (A1)
/A2: U1.8 (A2), U3.8 (A2), U4_SOCKET1.8 (A2)
/A3: U1.7 (A3), U3.7 (A3), U4_SOCKET1.7 (A3)
/A4: U1.6 (A4), U3.6 (A4), U4_SOCKET1.6 (A4)
/A5: U1.5 (A5), U3.5 (A5), U4_SOCKET1.5 (A5)
/A6: U1.4 (A6), U3.4 (A6), U4_SOCKET1.4 (A6)
/A7: U1.3 (A7), U3.3 (A7), U4_SOCKET1.3 (A7)
/A8: U1.25 (A8), U3.25 (A8), U4_SOCKET1.25 (A8)
/A9: U1.24 (A9), U3.24 (A9), U4_SOCKET1.24 (A9)
/A10: U1.21 (A10), U3.21 (A10), U4_SOCKET1.21 (A10)
/A11: U1.23 (A11), U3.23 (A11), U4_SOCKET1.23 (A11)
/A12: U1.2 (A12), U3.2 (A12), U4_SOCKET1.2 (A12)
/A13: U1.26 (A13), U2.2 (A0), U4_SOCKET1.26 (A13)
/A14: J2.2, U1.27 (A14), U2.3 (A1)
/A15: J2.3, U4.1, U4.2
/D0: U1.11 (D0), U3.11 (Q0), U4_SOCKET1.11 (D0)
/D1: U1.12 (D1), U3.12 (Q1), U4_SOCKET1.12 (D1)
/D2: U1.13 (D2), U3.13 (Q2), U4_SOCKET1.13 (D2)
/D3: U1.15 (D3), U3.15 (Q3), U4_SOCKET1.15 (D3)
/D4: U1.16 (D4), U3.16 (Q4), U4_SOCKET1.16 (D4)
/D5: U1.17 (D5), U3.17 (Q5), U4_SOCKET1.17 (D5)
/D6: U1.18 (D6), U3.18 (Q6), U4_SOCKET1.18 (D6)
/D7: U1.19 (D7), U3.19 (Q7), U4_SOCKET1.19 (D7)
/R/~W: J2.1, U3.27 (~WE)
/~A15: U1.22 (~OE), U2.1 (E), U2.15 (E), U3.22 (~OE), U4.3
/~RAMSEL: U2.4 (O0), U2.14 (A0), U3.20 (~CS)
/~ROMSEL: U1.20 (~CE), U2.11 (O1)
GND: J1.2, RAM_A13.1 (A), RAM_A14.1 (A), U1.14 (GND), U2.8 (GND), U2.13 (A1), U3.14 (GND), U4.7 (GND), U4_SOCKET1.14 (GND)
unnamed: J1.1, R15.2, U1.1 (A15)
unnamed: R13.2, RAM_A13.2 (B), U3.26 (A13)
unnamed: RAM_A14.2 (B), U3.1 (A14)
VCC: R13.1, R15.1, U1.28 (VCC), U2.16 (VCC), U3.28 (VCC), U4.4, U4.5, U4.9, U4.10, U4.12, U4.13, U4.14 (VCC), U4_SOCKET1.28 (VCC)

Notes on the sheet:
When using 6264 for U3: install R13 and open RAM_A13 (it's CE2 line) When using 62256 for U3: Same as 6264 or R13 can be omitted and RAM_A13 shorted. If 2 bit port is available then keep RAM_A13/14 open and connect pins 2 to switch between 8K banks.
J2: - A14 from CPU (U2) pin 21 or U7 pin 7 - A15 from CPU (U2) pin 22 or U7 pin 6 - R/~{W} from onboard RAM (U5) pin 21 or or U3 pin 19
J1: - switch chooses ROM from 32K half of 27C512 closed = bottom half open = top half
unused gates

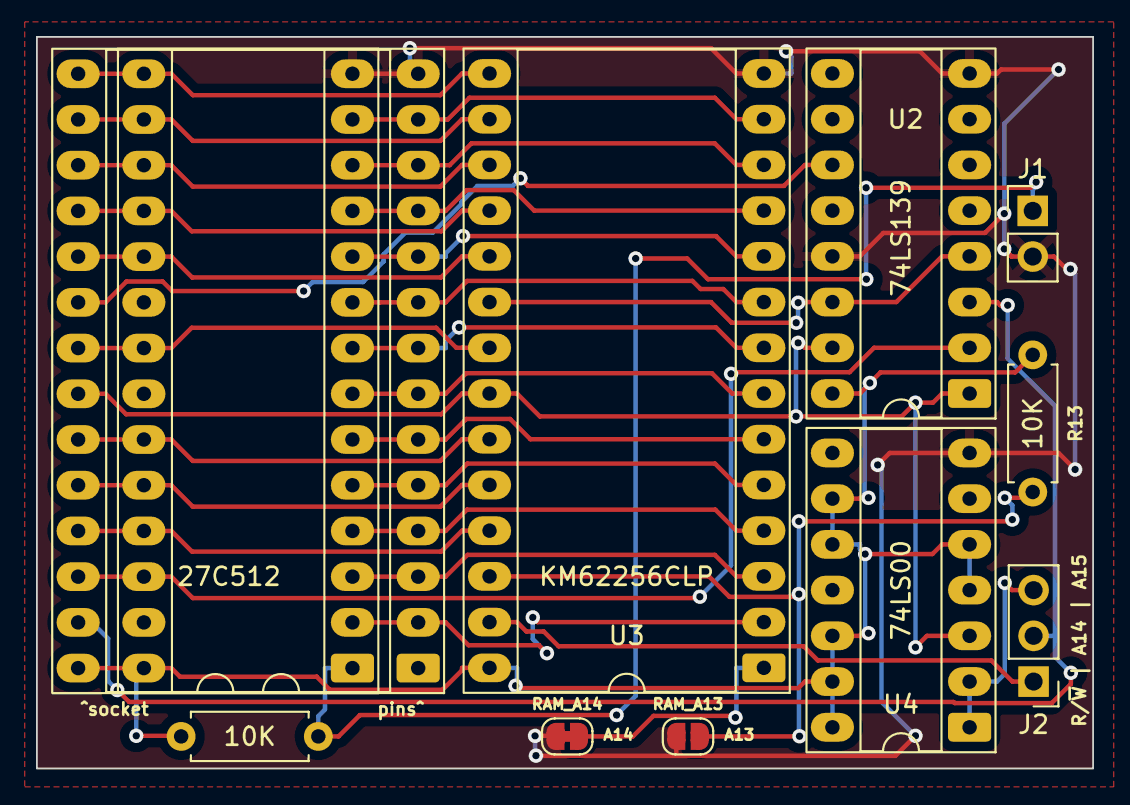
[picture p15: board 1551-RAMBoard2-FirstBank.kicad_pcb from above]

Board: 2 copper layers, 58.7 x 40.6 mm, 11 parts (0 on the bottom side), 33 nets.

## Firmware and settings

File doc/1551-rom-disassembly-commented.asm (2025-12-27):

; Note: additional comments were added based on automatic comparison with
;       All About Your 1541. Trust but verify!

;
; 	    The Complete Commodore 1551 ROM disassembly
;			by Attila Grósz
;		     http://yape.plus4.net
;                  grosza_AT_hotmail_DOT_com
;
;			   revision 0
;
;	      Based on 1541 ROM disassembly from AAY1541
;
; ADDITIONAL COMMENTS:
;   - Cross-references to 1541 ROM addresses (AAY1541) added where applicable
;   - 1551 uses TIA chip ($4000) instead of VIAs ($1800/$1C00 on 1541)
;   - 1551 runs at 2MHz (vs 1MHz on 1541), enabling on-the-fly GCR decoding
;   - Zero page addresses differ significantly from 1541 (see mapping guide)
;
;

; ROM is mapped between $C000-$FFFF in the drive memory
	ORG $C000 - 2
	DW  $C000
; Zeropage vectors
zp0E = $0E ;(3)
zp12 = $12 ;(1)
zp15 = $15 ;(7)
zp1E = $1E ;(24)
zp20 = $20 ;(37)
zp27 = $27 ;(38) address of current buffer
zp32 = $32 ;(3)
zp34 = $34 ;(3)
zp45 = $45 ;(9)
zp49 = $49 ;(15)
zp4E = $4E ;(6)
zp59 = $59 ;(4)
zp6A = $6A ;(3)
zp6C = $6C ;(25)
zp6E = $6E ;(79)
zp70 = $70 ;(22)
zp74 = $74 ;(8)
zp7F = $7F ;(42) counter for erased files
zp81 = $81 ;(17)
zp82 = $82 ;(11)
zp8D = $8D ;(85)
zpA4 = $A4 ;(9)  Pointer: Next byte in command buffer [0200]
zpA6 = $A6 ;(10)
zpC0 = $C0 ;(4)
zpC4 = $C4 ;(3)
zpC9 = $C9 ;(2)
zpCB = $CB ;(1)
zpE5 = $E5 ;(1)
;-------------------
; Zeropage variables
;-------------------
;
zp00 = $00 ;(9)  cpu data direction register
zp01 = $01 ;(65) cpu port, FDC control register
; bit 0: drive head stepper 0 (STP)
; bit 1: drive head stepper 1 (STP)
; bit 2: drive motor on/off (MTR)
; bit 3: drive LED (ACT)
; bit 4: write protect sensor (WPS)
; bit 5: density select #0 (DS0)
; bit 6: density select #1 (DS1)
; bit 7: byte latched (1 - yes, 0 - no)
;
zp02 = $02 ;(14) Command code for buffer 0
zp03 = $03 ;(2)  Command code for buffer 1
zp04 = $04 ;(3)  Command code for buffer 2
zp05 = $05 ;(1)  Command code for buffer 3
zp06 = $06 ;(6)  Command code for buffer 4
zp07 = $07 ;(2)  Command code for buffer 5 (unused)
zp08 = $08 ;(6)	 Track and sector for buffer 0
zp09 = $09 ;(5)
zp0A = $0A ;(2)	 Track and sector for buffer 1
zp0C = $0C ;(1)	 Track and sector for buffer 2
zp14 = $14 ;(6) disk id 1
zp18 = $18 ;(6) block header id 1
zp19 = $19 ;(6) block header id 2
zp1A = $1A ;(5) track blockheader
zp1B = $1B ;(5) sector blockheader
zp1C = $1C ;(3) checksum of block header
zp1D = $1D ;(5) current drive number (always 0)
zp22 = $22 ;(8) write protect flag for drive 0 or 1
zp23 = $23 ;(2) write protect flag for drive 1 (unused)
zp24 = $24 ;(4)
zp26 = $26 ;(1)
zp29 = $29 ;(6) FDC current track
zp2B = $2B ;(14) drive status flag
           ;     bit 5: drive motor
           ;     bit 6: stepper motor
           ;     bit 7: drive ready
zp2D = $2D ;(10)
zp2E = $2E ;(19)
zp2F = $2F ;(2)
zp30 = $30 ;(8)
zp31 = $31 ;(7)
zp36 = $36 ;(4)
zp37 = $37 ;(4)
zp38 = $38 ;(5)
zp39 = $39 ;(7)
zp3A = $3A ;(2) temporary stack storage
zp3B = $3B ;(9) stepper motor direction (<$80 inner, >=$80 outer)
zp3C = $3C ;(6)
zp3D = $3D ;(3) last sector read
zp3E = $3E ;(2) next sector to be read
zp3F = $3F ;(5) GCR/BIN indicator for current buffer
zp40 = $40 ;(11) current track
zp41 = $41 ;(17)
zp42 = $42 ;(18)
zp43 = $43 ;(20)
zp44 = $44 ;(18)
zp47 = $47 ;(4)
zp48 = $48 ;(9)
zp4B = $4B ;(4)
zp4C = $4C ;(3)
zp4D = $4D ;(5)
zp50 = $50 ;(5)
zp51 = $51 ;(3)
zp52 = $52 ;(5)
zp53 = $53 ;(10)
zp54 = $54 ;(9)
zp55 = $55 ;(2) drive LED flash counter
zp56 = $56 ;(2)
zp57 = $57 ;(6)
zp58 = $58 ;(6)
zp5B = $5B ;(4) TALK flag
zp5C = $5C ;(4) LISTEN flag (1/0)
zp5D = $5D ;(4) format string of disk after init (2A)
zp5E = $5E ;(1)
zp5F = $5F ;(6)
zp61 = $61 ;(2) ROM-test checksum
zp62 = $62 ;(4)
zp63 = $63 ;(3)
zp65 = $65 ;(1)
zp66 = $66 ;(3) device number
zp68 = $68 ;(6)
zp69 = $69 ;(4)
zp72 = $72 ;(4)
zp76 = $76 ;(2) LED blink flag (#$E0 = on)
zp77 = $77 ;(2) last track number
zp78 = $78 ;(69) current drive number
zp79 = $79 ;(86) current track
zp7A = $7A ;(83) current sector
zp7B = $7B ;(102) current channel
zp7C = $7C ;(58) secondary address
zp7D = $7D ;(6)  secondary address from computer
zp7E = $7E ;(26)
zp84 = $84 ;(7)
zp85 = $85 ;(3)
zp86 = $86 ;(3)
zp87 = $87 ;(2)
zp89 = $89 ;(12)
zp8A = $8A ;(7)
zp8B = $8B ;(2)
zp8C = $8C ;(1)
zp8F = $8F ;(1)
zp91 = $91 ;(5) pointer in record
zp92 = $92 ;(15)
zp93 = $93 ;(14)
zp94 = $94 ;(7)
zp95 = $95 ;(10) EOI
zp96 = $96 ;(2)
zp97 = $97 ;(8)
zp98 = $98 ;(26) buffer number
zp99 = $99 ;(6)	 Pointer to first filename
zp9A = $9A ;(55)
zp9B = $9B ;(6)
zpA8 = $A8 ;(38)
zpAC = $AC ;(1)
zpAD = $AD ;(2)
zpAE = $AE ;(1)
zpAF = $AF ;(24)
zpB5 = $B5 ;(1)
zpB6 = $B6 ;(10)
zpBC = $BC ;(9)
zpC2 = $C2 ;(13)
zpC8 = $C8 ;(10)
zpCE = $CE ;(18)
zpD2 = $D2 ;(1)
zpD3 = $D3 ;(1)
zpD4 = $D4 ;(4)
zpD8 = $D8 ;(1)
zpD9 = $D9 ;(7)
zpDA = $DA ;(2)
zpDD = $DD ;(1)
zpDE = $DE ;(7)
zpDF = $DF ;(2)
zpE2 = $E2 ;(1)
zpE3 = $E3 ;(18)
zpE4 = $E4 ;(5)
zpE7 = $E7 ;(1)
zpE8 = $E8 ;(18)
zpE9 = $E9 ;(2)
zpEB = $EB ;(1)
zpED = $ED ;(12)
zpF1 = $F1 ;(1)
zpF3 = $F3 ;(13)
zpF7 = $F7 ;(1)
zpF8 = $F8 ;(3)
zpF9 = $F9 ;(12)
zpFA = $FA ;(12)
zpFB = $FB ;(10)
zpFC = $FC ;(4)
zpFD = $FD ;(5)
zpFE = $FE ;(3)
zpFF = $FF ;(9)
;
; GCR overflow area and stack $100-$1ff
;
V_0100 = $0100
V_0101 = $0101
V_0102 = $0102
V_0103 = $0103
V_0111 = $0111
V_0112 = $0112
V_011B = $011B
V_01A9 = $01A9
V_01FF = $01FF
;
; Command buffer, parser, tables, variables $200-$2ff
;
V_0200 = $0200  ; input buffer $0200-$0229 for command string,
L_0201 = $0201
V_0202 = $0202
V_0203 = $0203
V_0204 = $0204
V_0205 = $0205
V_0206 = $0206
V_022A = $022A	; command number temporary storage (Command code)
V_022B = $022B	; Logical index, channel 0
V_022C = $022C	; Logical index, channel 1
V_022D = $022D	; Logical index, channel 2
V_023A = $023A
V_023B = $023B
V_023C = $023C
V_023D = $023D
V_023E = $023E
V_0243 = $0243
V_0244 = $0244
V_0249 = $0249 	; end of error message
V_024A = $024A 	; active data/file type
V_024B = $024B 	; filename/string length
V_024C = $024C	; Temp. channel number (secondary address)
V_024D = $024D	; Current work with drive number
V_024E = $024E	; Work area to find the best sector
V_024F = $024F	; Buffer allocated
V_0250 = $0250	; Buffer allocated
V_0251 = $0251	; Flag: BAM changed, drive 0
V_0253 = $0253	; Flag for directory entry found (FF = Not found, 00 = Found)
V_0254 = $0254	; Flag for directory output
V_0255 = $0255	; Flag: Waiting for command
V_0256 = $0256  ; buffer allocation register
V_0257 = $0257	; Last used buffer
V_0258 = $0258	; Record length
V_0259 = $0259	; Track of side sector
V_025A = $025A	; Sector of side sector
V_025B = $025B	; Last work (buffers) $025B-$025F
V_0260 = $0260	; Directory sector (buffers) $0260-$0265
V_0266 = $0266	; File's index in directory (buffers) $0266-$026B
V_026C = $026C  ; error flag, counter for led flash?
V_026E = $026E  ; last program's drive number
V_026F = $026F  ; last sector number
V_0270 = $0270  ; temporary storage for channel number
V_0272 = $0272  ; number of blocks free
V_0273 = $0273
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

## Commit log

2025-12-21 moving to 1551
    [1541-RAMBoard2-FirstBank-B_Cu.gbl, 1541-RAMBoard2-FirstBank-B_Mask.gbs, 1541-RAMBoard2-FirstBank-B_Paste.gbp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]
2025-12-21 1551 photos and schematics
2025-12-21 first attempt
    [1551-RAMBoard2-FirstBank.kicad_pcb, 1551-RAMBoard2-FirstBank.kicad_sch]
2025-12-21 first try
    [1551-RAMBoard2-FirstBank-B_Cu.gbl, 1551-RAMBoard2-FirstBank-B_Mask.gbs, 1551-RAMBoard2-FirstBank-B_Paste.gbp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]
2025-12-27 remove KiCad backup files
2025-12-27 ignore KiCad backup files
2025-12-27 final touches, support for 6264 (8K) and 62256 (32K)
    [1551-RAMBoard2-FirstBank-B_Cu.gbl, 1551-RAMBoard2-FirstBank-B_Mask.gbs, 1551-RAMBoard2-FirstBank-B_Paste.gbp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]
2025-12-27 1551 track cache patches, no need for GCR decoding tables, this is already contained in 1551 ROM
2026-01-11 PCB image
2026-02-01 updates after real hardware test, clarify R/W connection info
    [1551-RAMBoard2-FirstBank-B_Cu.gbl, 1551-RAMBoard2-FirstBank-B_Mask.gbs, 1551-RAMBoard2-FirstBank-B_Paste.gbp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]
2026-02-01 schematic with drawing sheet
